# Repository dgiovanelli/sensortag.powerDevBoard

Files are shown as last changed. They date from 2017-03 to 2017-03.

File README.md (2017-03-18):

# sensortag.powerDevPack

Devboard for adding lipo battery. It features battery charger through micro USB, high efficiency DCDC regulator and UART to USB converter through a FTDI chip. 

It has been designed for cc2650 sensorTag, but it should work also with the other versions till the so called "SKIN" connector keeps the same pinout settings.
The output voltage is fixed by the DCDC to 3.75 volt, it can be reduced acting on the values of RTPS1, RTPS2 and RTPS3. See TPS62737 datasheet for details.
Note that the AON battery monitor won't work because of the DCDC. The battery voltage can be measured usign the appropriate circuit on the powerDevBoard. To activate it set DP2 pin to 'HIGH', then read analog voltage at DP3 pin. The actual battery voltage is twice the voltage measured at DP3. The battery measurement circuit absorbs about 10uA from the battery, when not used set DP2 to "LOW".

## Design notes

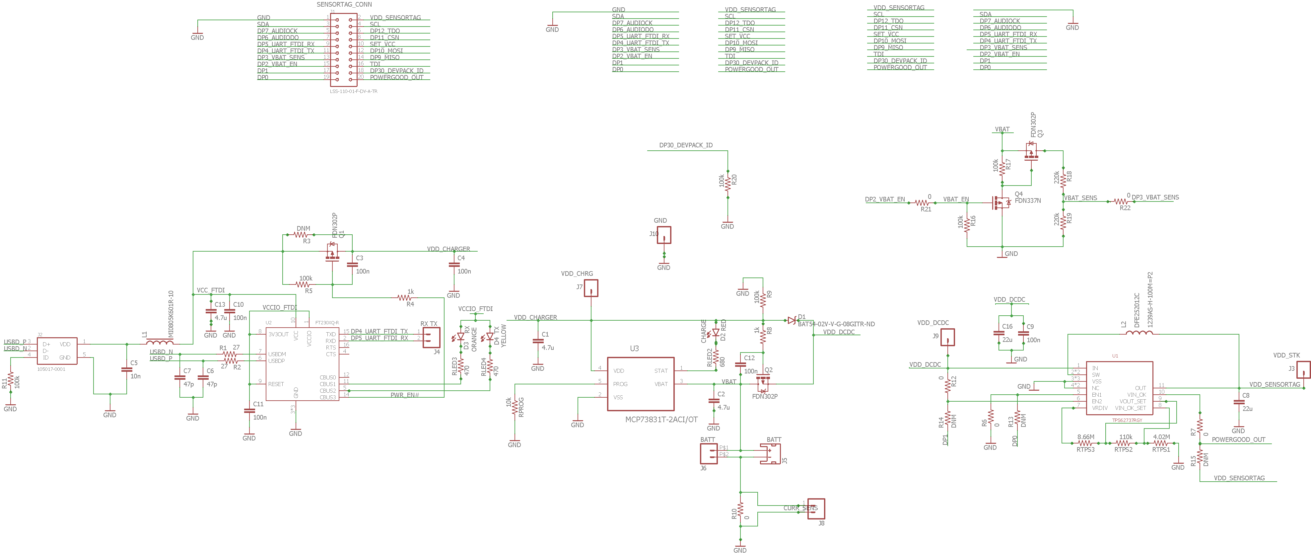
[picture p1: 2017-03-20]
HARDWARE/doc/schematic.png

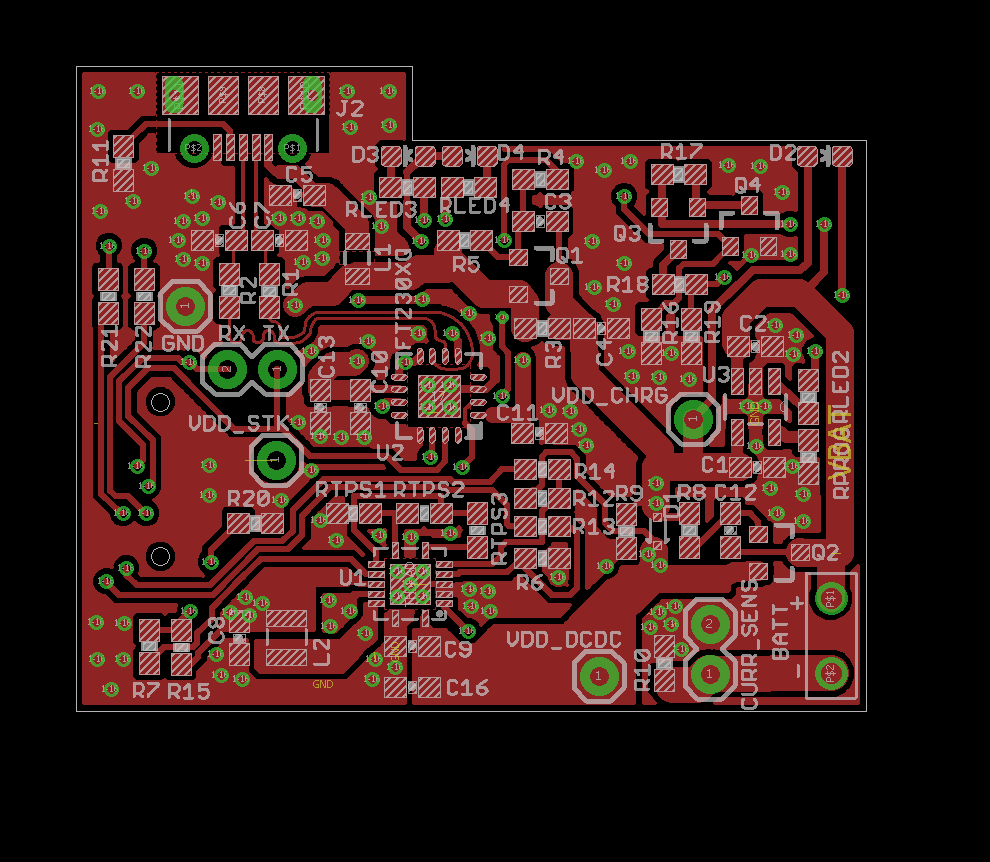
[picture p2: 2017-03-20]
HARDWARE/doc/pcb_top.png

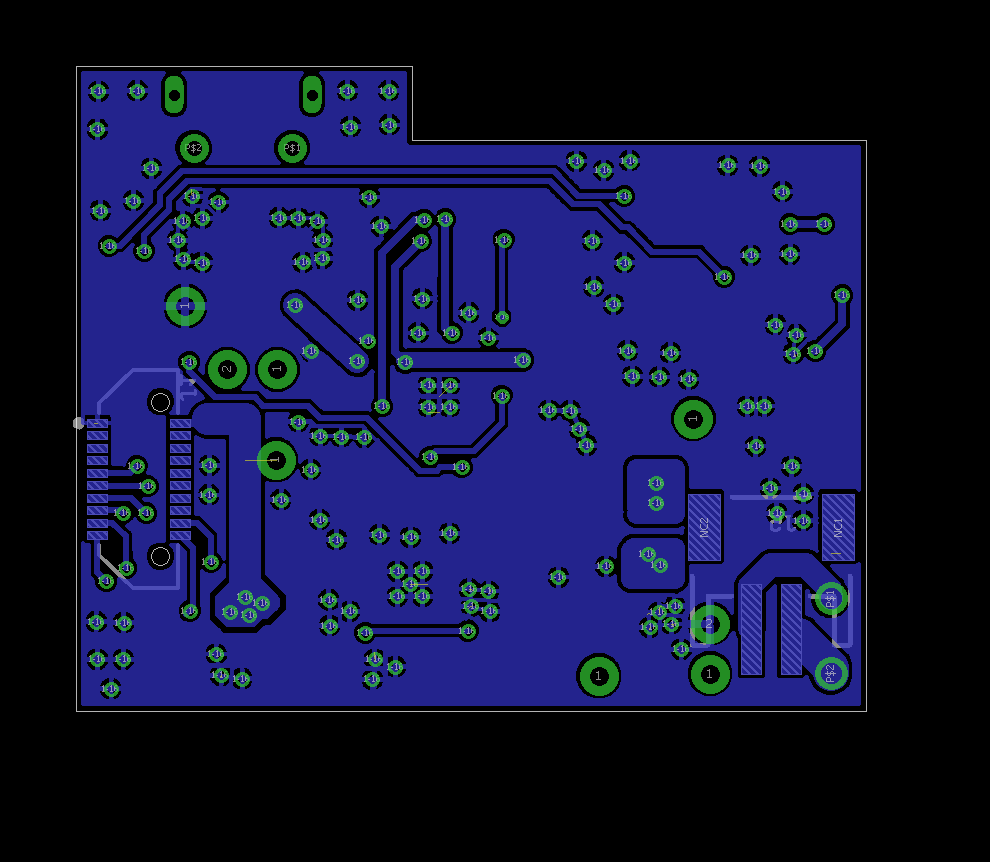
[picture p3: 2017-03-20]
HARDWARE/doc/pcb_bott.png

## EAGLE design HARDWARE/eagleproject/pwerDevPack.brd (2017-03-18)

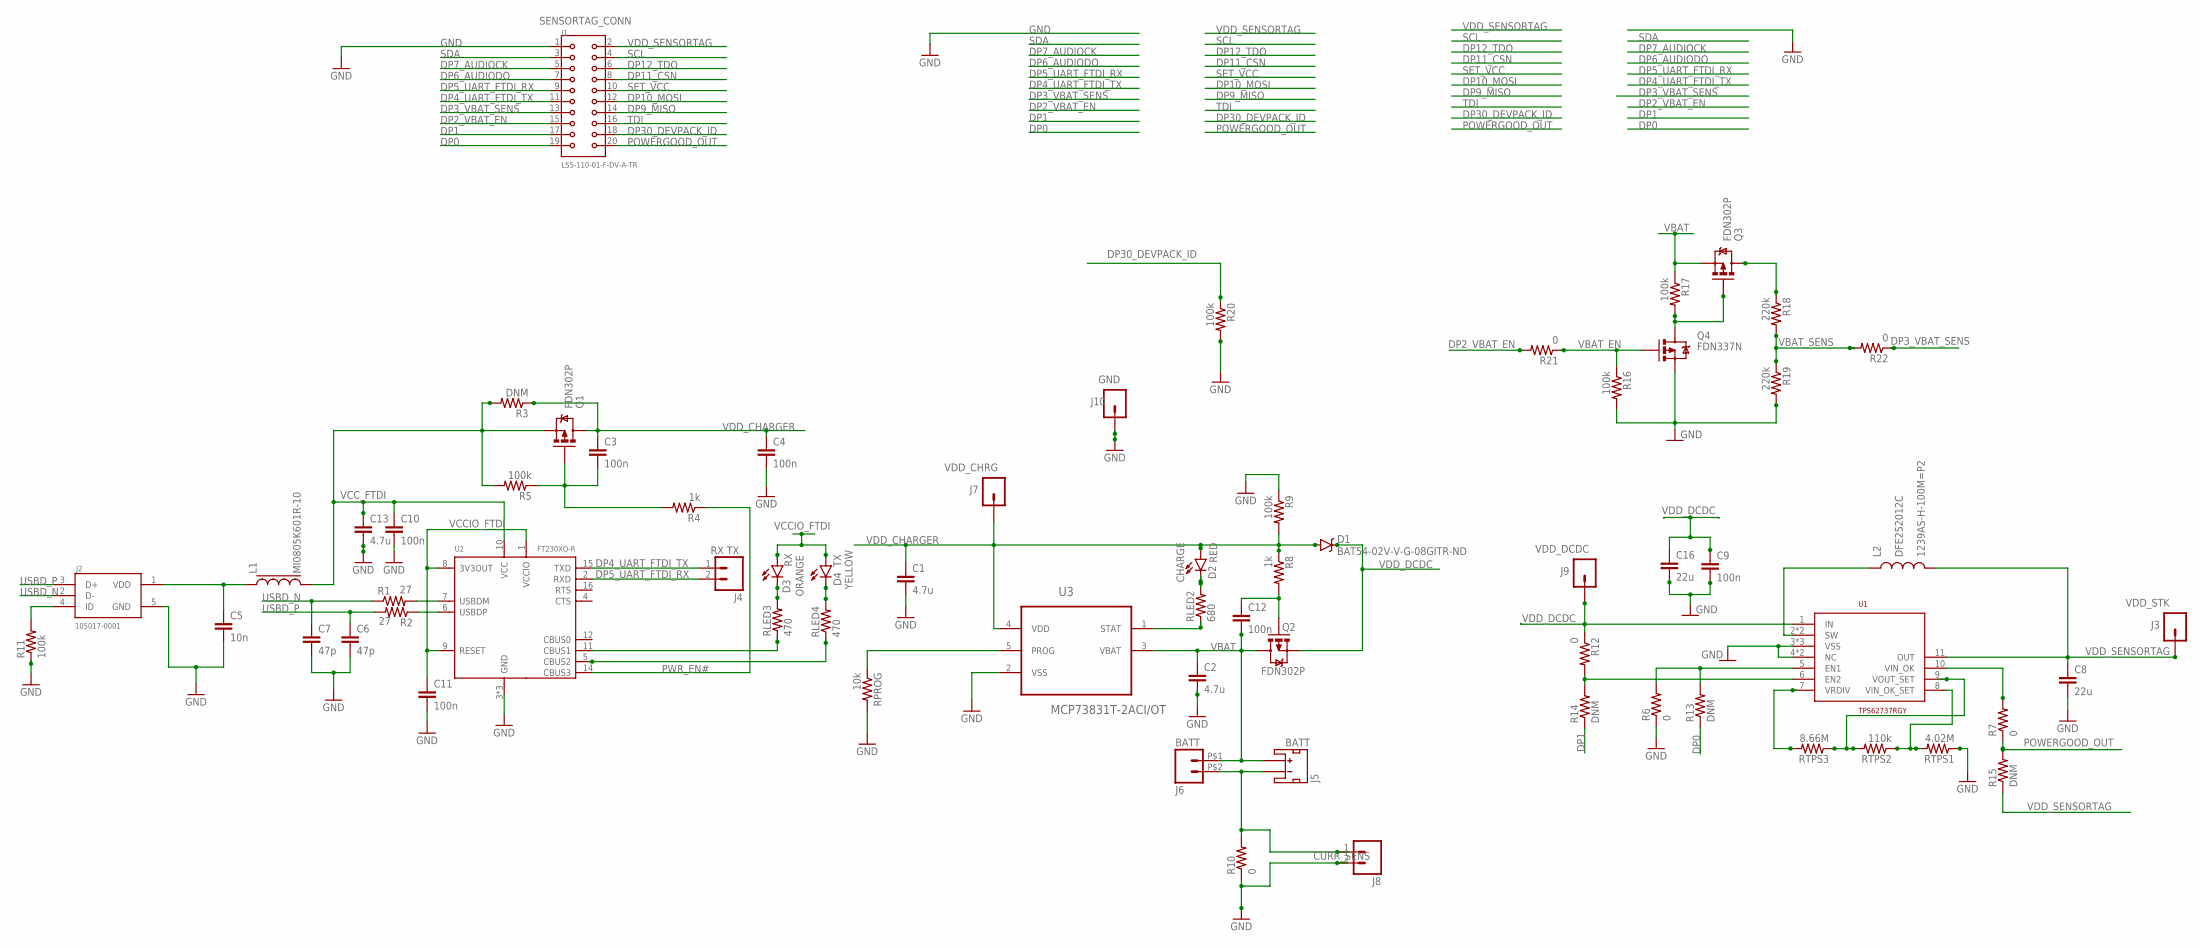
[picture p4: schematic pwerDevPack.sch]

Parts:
C1, C2, C13: 4.7u; 0603-CAP
C3, C4, C9, C10, C11, C12: 100n; 0603-CAP
C5: 10n; 0603-CAP
C6, C7: 47p; 0603-CAP
C8, C16: 22u; 0603-CAP
D1: BAT54-02V-V-G-08GITR-ND; SOD-523
D2: RED; LED-0603
D3: ORANGE; LED-0603
D4: YELLOW; LED-0603
J1: LSS-110-01-F-DV-A-TR; SAMTEC_LSS-110-01-F-DV-A-TR
J2: 105017-0001; MOLEX_105017-0001
J3, J7, J9, J10: M01PTH; 1X01
J4, J8: M02PTH; 1X02
J5: S2B-PH-SM4-TB; JST-2-SMD
J6: M02PTH2; 1X02_BIG
L1: MI0805K601R-10; 0805
L2: 1239AS-H-100M=P2; DFE252012C
Q1, Q2, Q3: FDN302P; SOT23-3
Q4: FDN337N; SOT23-3
R1, R2: 27; 0603-RES
R3, R13, R14, R15: DNM; 0603-RES
R4, R8: 1k; 0603-RES
R5, R9, R11, R16, R17, R20: 100k; 0603-RES
R6, R7, R10, R12, R21, R22: 0; 0603-RES
R18, R19: 220k; 0603-RES
RLED2: 680; 0603-RES
RLED3, RLED4: 470; 0603-RES
RPROG: 10k; 0603-RES
RTPS1: 4.02M; 0603-RES
RTPS2: 110k; 0603-RES
RTPS3: 8.66M; 0603-RES
U1: TPS62737RGY; QFN14
U2: FT230XQ-R; QFN16
U3: MCP73831T-2ACI/OT; SOT95P280X145-5N

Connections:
CHARGER_STAT: RLED2.1, U3.1 (STAT)
DP0: J1.19, R13.1
DP1: J1.17, R14.1
DP2_VBAT_EN: J1.15, R21.2
DP3_VBAT_SENS: J1.13, R22.1
DP4_UART_FTDI_TX: J1.11, J4.1, U2.15 (TXD)
DP5_UART_FTDI_RX: J1.9, J4.2, U2.2 (RXD)
DP6_AUDIODO: J1.7
DP7_AUDIOCK: J1.5
DP9_MISO: J1.14
DP10_MOSI: J1.12
DP11_CSN: J1.8
DP12_TDO: J1.6
DP30_DEVPACK_ID: J1.18, R20.1
GND: C1.2, C2.2, C4.2, C5.2, C6.2, C7.2, C8.2, C9.2, C10.2, C11.2, C13.2, C16.2, J1.1, J2.5 (GND), J8.2, J10.1, Q4.2 (S), R6.1, R9.1, R10.1, R11.1, R16.2, R19.2, R20.2, RPROG.2, RTPS1.1, U1.3 (VSS), U1.4 (NC), U1.12 (VSS), U1.14 (NC), U1.TH_PAD (VSS), U2.3 (GND), U2.13 (GND), U2.17 (GND), U3.2 (VSS)
GND_BAT: J5.1 (-), J6.P$2 (2), J8.1, R10.2
unnamed: D3.C, RLED3.2
unnamed: C5.1, J2.1 (VDD), L1.1
unnamed: C3.2, Q1.1 (G), R4.2, R5.1
unnamed: RTPS1.2, RTPS2.1, U1.8 (VIN_OK_SET)
unnamed: R6.2, R13.2, U1.5 (EN1)
unnamed: RPROG.1, U3.5 (PROG)
unnamed: Q3.3 (D), R18.1
unnamed: R12.2, R14.2, U1.6 (EN2)
unnamed: L2.P$1 (1), U1.2 (SW), U1.13 (SW)
unnamed: C12.1, Q2.1 (G), R8.2
unnamed: D2.C, RLED2.2
unnamed: D4.C, RLED4.2
unnamed: Q3.1 (G), Q4.3 (D), R17.2
unnamed: J2.4 (ID), R11.2
unnamed: RLED3.1, U2.11 (CBUS1)
unnamed: R7.2, U1.10 (VIN_OK)
unnamed: RTPS3.2, U1.7 (VRDIV)
unnamed: RLED4.1, U2.5 (CBUS2)
unnamed: RTPS2.2, RTPS3.1, U1.9 (VOUT_SET)
POWERGOOD_OUT: J1.20, R7.1, R15.2
PWR_EN#: R4.1, U2.14 (CBUS3)
SCL: J1.4
SDA: J1.3
SET_VCC: J1.10
TDI: J1.16
USBDR_N: R1.2, U2.7 (USBDM)
USBDR_P: R2.1, U2.6 (USBDP)
USBD_N: C7.1, J2.2 (D-), R1.1
USBD_P: C6.1, J2.3 (D+), R2.2
VBAT: C2.1, C12.2, J5.2 (+), J6.P$1 (1), Q2.3 (D), Q3.2 (S), R17.1, U3.3 (VBAT)
VBAT_EN: Q4.1 (G), R16.1, R21.1
VBAT_SENS: R18.2, R19.1, R22.2
VCCIO_FTDI: C11.1, D3.A, D4.A, U2.1 (VCCIO), U2.8 (3V3OUT), U2.9 (RESET)
VCC_FTDI: C10.1, C13.1, L1.2, Q1.2 (S), R3.2, R5.2, U2.10 (VCC)
VDD_CHARGER: C1.1, C3.1, C4.1, D1.A, D2.A, J7.1, Q1.3 (D), R3.1, R8.1, R9.2, U3.4 (VDD)
VDD_DCDC: C9.1, C16.1, D1.C, J9.1, Q2.2 (S), R12.1, U1.1 (IN)
VDD_SENSORTAG: C8.1, J1.2, J3.1, L2.P$2 (2), R15.1, U1.11 (OUT)

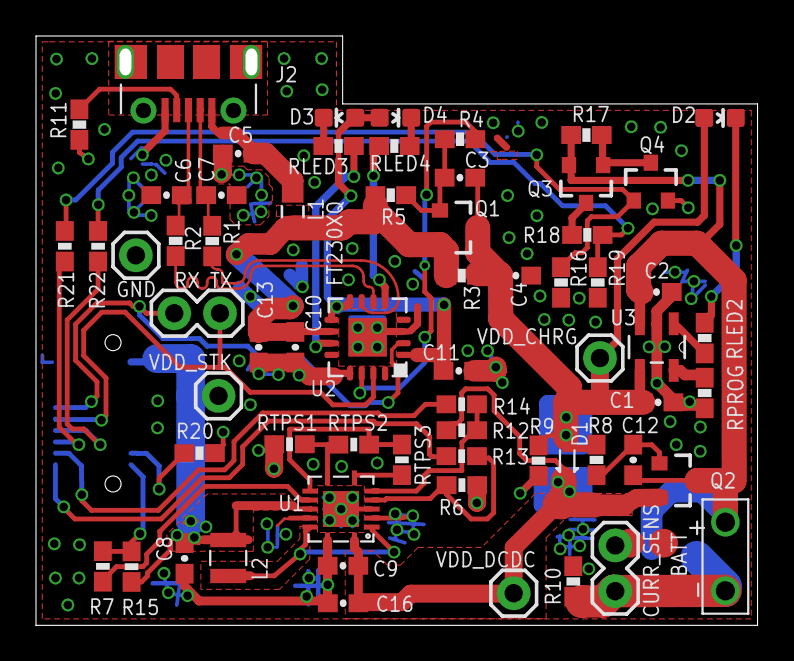
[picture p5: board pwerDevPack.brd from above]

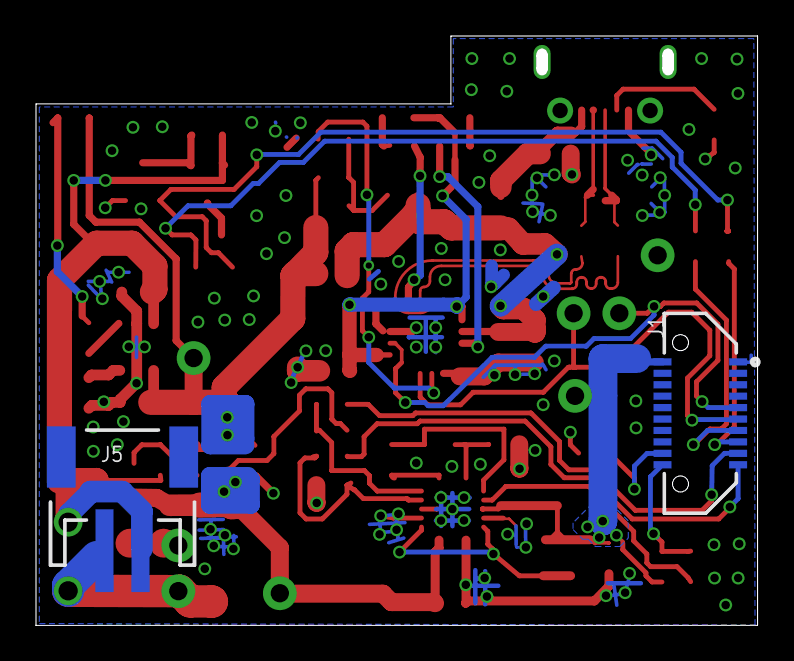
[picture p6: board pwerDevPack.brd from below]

Board: 2 copper layers, 40.1 x 32.7 mm, 66 parts (2 on the bottom side), 43 nets.

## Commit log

2017-03-18 First commit. Here the first working version of the board.
    The board has been tested but not extensively.
    Documentation is missing for now.
    [pwerDevPack.brd, pwerDevPack.sch]
2017-03-20 Adding schematic and pcb images

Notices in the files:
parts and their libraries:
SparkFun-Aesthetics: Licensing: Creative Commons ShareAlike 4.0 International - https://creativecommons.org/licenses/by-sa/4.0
